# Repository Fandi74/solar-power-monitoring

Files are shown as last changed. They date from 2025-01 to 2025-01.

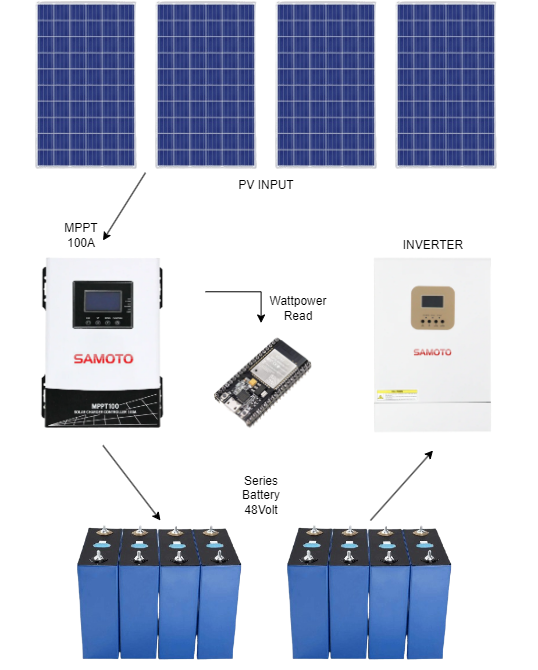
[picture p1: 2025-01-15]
asset/PV.png

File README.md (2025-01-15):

***Solar Monitoring System***

This repository contains the source code for a Solar Monitoring System using ESP32 for data acquisition, storage, and logging. The system reads data from solar panels, calculates power values, and logs the information locally or sends it to the cloud.

**Features**
- Real-time monitoring of voltage, current, and power from two solar panels.
- Data logging to an SD card in JSON format.
- Time synchronization with NTP servers.
- LCD display for live data visualization.
- Modular design with FreeRTOS tasks.

**Project Structure**
- main.cpp: ESP32-based code for the actual deployment.
- hardware/: Contains schematics, footprints PCBs, Simulation.

**Software Dependencies**

- PlatformIO (for development).
- Libraries:
  - Adafruit_ADS1X15
  - ArduinoJson
  - LiquidCrystal_I2C
  - WiFi
  - HTTPClient
  - RTC3231
- Proteus for simulation (using Arduino Uno).

**Future Enhancements**
- Implement cloud integration for remote monitoring.
- Add additional panels and sensors for scalability.
- Enhance data visualization with a web dashboard.

****I Made all of this just for fun****
Feel free give any feedback

**3D PCB**



**Schematic**

Solar Panel Monitoring_page-0001

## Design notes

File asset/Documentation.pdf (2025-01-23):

# com/Fandi74

# Solar Panel Power Monitoring

## Component

### 1. ESP32 WROOVER 32E

The central processing unit of the power monitoring. Manages sensor data collection, data processing, and processing. The ESP32 is responsible for coordinating all the connected components, executing the main program logic, and ensuring that data is accurately read from sensors.

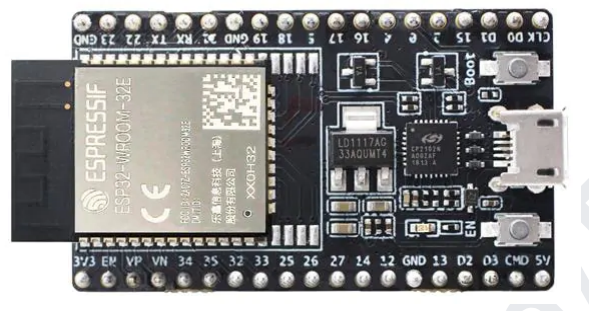
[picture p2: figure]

### 2. Green PCB

The green PCB serves as the foundation of the solar panel power monitoring, ensuring all components are interconnected and can function cohesively. Ensure all

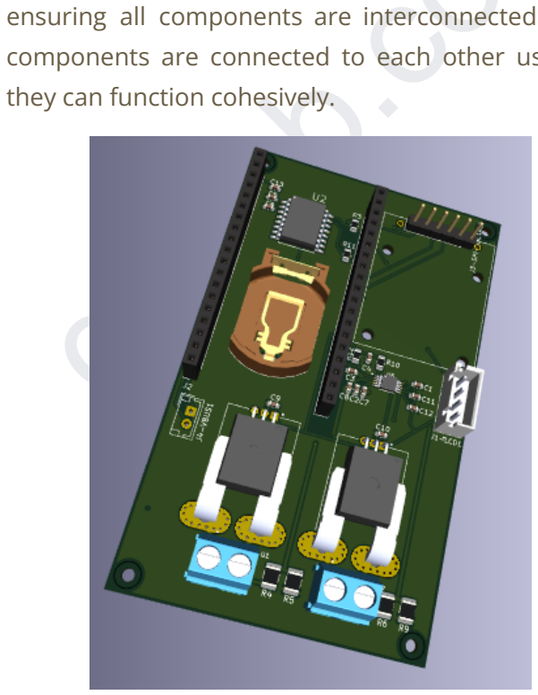
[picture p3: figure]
github.; they can function cohesively.

components are connected to each other using JST and fishbone connectors so that

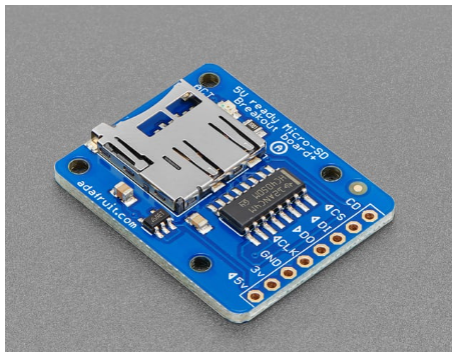
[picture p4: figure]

# com/Fandi74

### 3. Adafruit SD Card Module

A microSD card module is a small device that allows interface a microSD card with the ESP32s. The module enables read from and write to the microSD card, which can be used for storing data such as logs, configuration files, or sensor readings.

### 4. ACS758

ACS758 current sensor is used in solar power monitoring systems to measure the current generated by solar panels. By measuring the current flowing through the wires, the ACS758 provides an analog voltage output proportional to the current. This output is read by a microcontroller like the ESP32 via an ADC, where the data is processed to calculate real-time current.

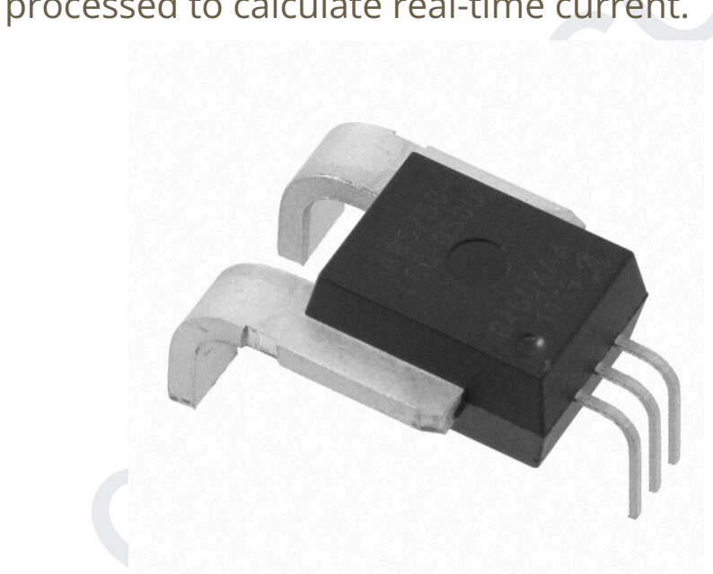
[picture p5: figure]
github.

### 5. DS3231 + CR2023 Battery

The DS3231 is a highly accurate real-time clock (RTC) module. commonly used in embedded systems to keep track of time, even when the main power is turned off. It uses an I2C communication protocol to interface with microcontrollers like the ESP32. The module is powered by a CR2032 coin cell battery, which ensures that the clock continues to run even when the main system power is removed.

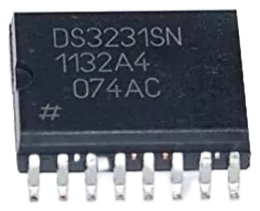
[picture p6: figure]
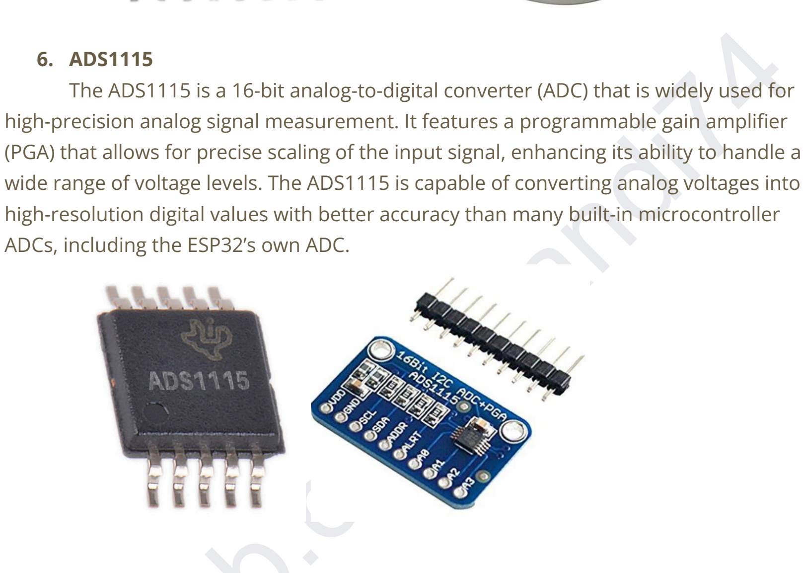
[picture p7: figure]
com/Fandi74; 6. ADS1115; ADCs, including the ESP32’s own ADC.

github.

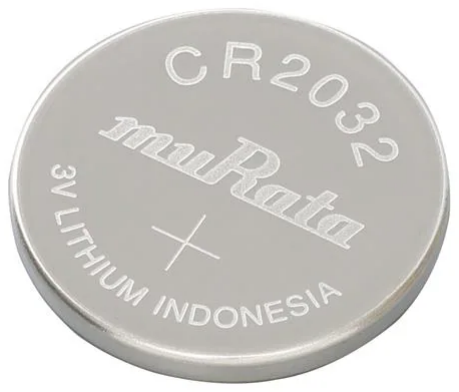
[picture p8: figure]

The ADS1115 is a 16-bit analog-to-digital converter (ADC) that is widely used for high-precision analog signal measurement. It features a programmable gain amplifier (PGA) that allows for precise scaling of the input signal, enhancing its ability to handle a wide range of voltage levels. The ADS1115 is capable of converting analog voltages into high-resolution digital values with better accuracy than many built-in microcontroller

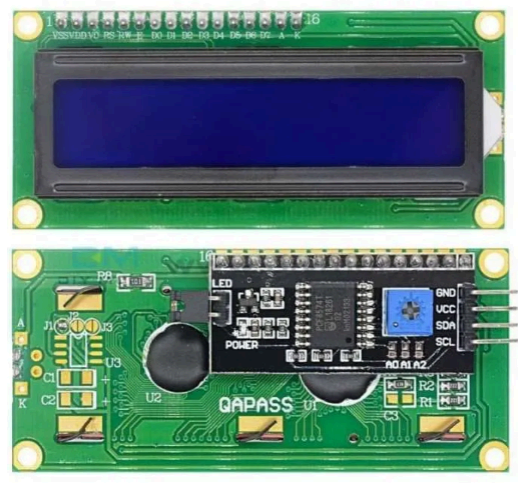
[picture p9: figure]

### 7. LCD I2C

An I2C LCD is an LCD (Liquid Crystal Display) that uses the I2C (Inter-Integrated Circuit) communication protocol for data transfer. This simplifies wiring and reduces the number of pins needed compared to traditional parallel LCDs.

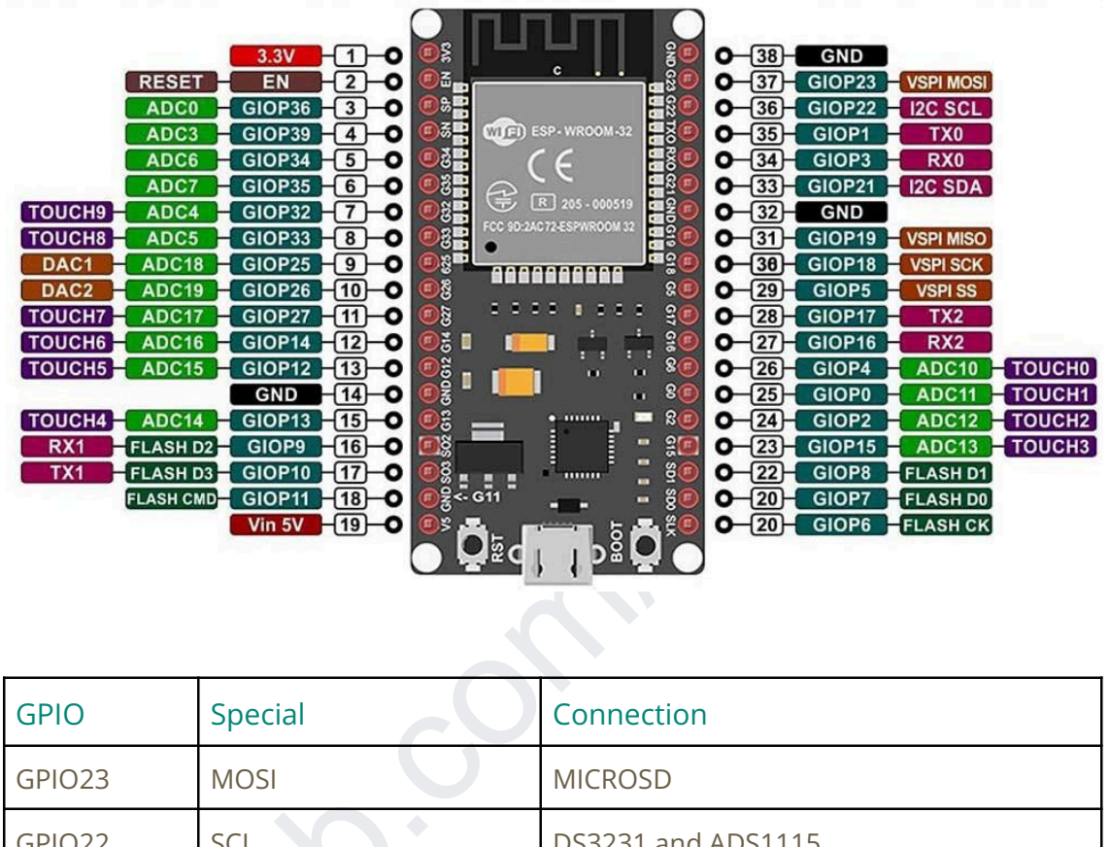
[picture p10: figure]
com/Fandi74; GPIO; Special; Connection; GPIO23; MOSI; MICROSD

github.

## Device Configuration

## ESP32 Configuration

GPIO22 | SCL | DS3231 and ADS1115
GPIO21 | SDA | DS3231 and ADS1115
GPIO19 | MISO | MICROSD
GPIO18 | SCK | MICROSD
GPIO5 | SS | MICROSD
GPIO15 | Alert | ADS1115 Alert

# com/Fandi74

## ADS1115 Configuration

GPIO | Special | Connection
A0 | Channel 0 | VDC SOLAR PANEL 1
A1 | Channel 1 | VDC SOLAR PANEL 2
A2 | Channel 2 | ACS VIOUT 1
A3 | Channel 3 | ACS VIOUT 2

## Block Diagram

## Solar Panel System Diagram

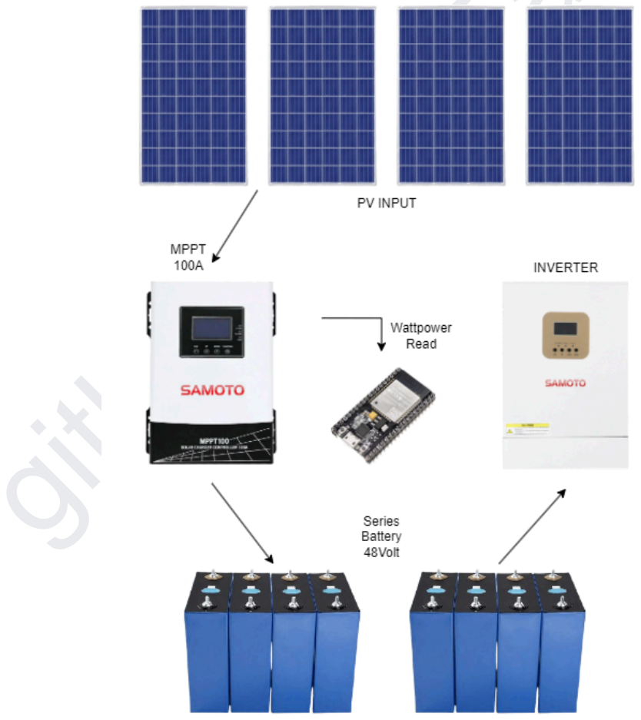
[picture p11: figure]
github.

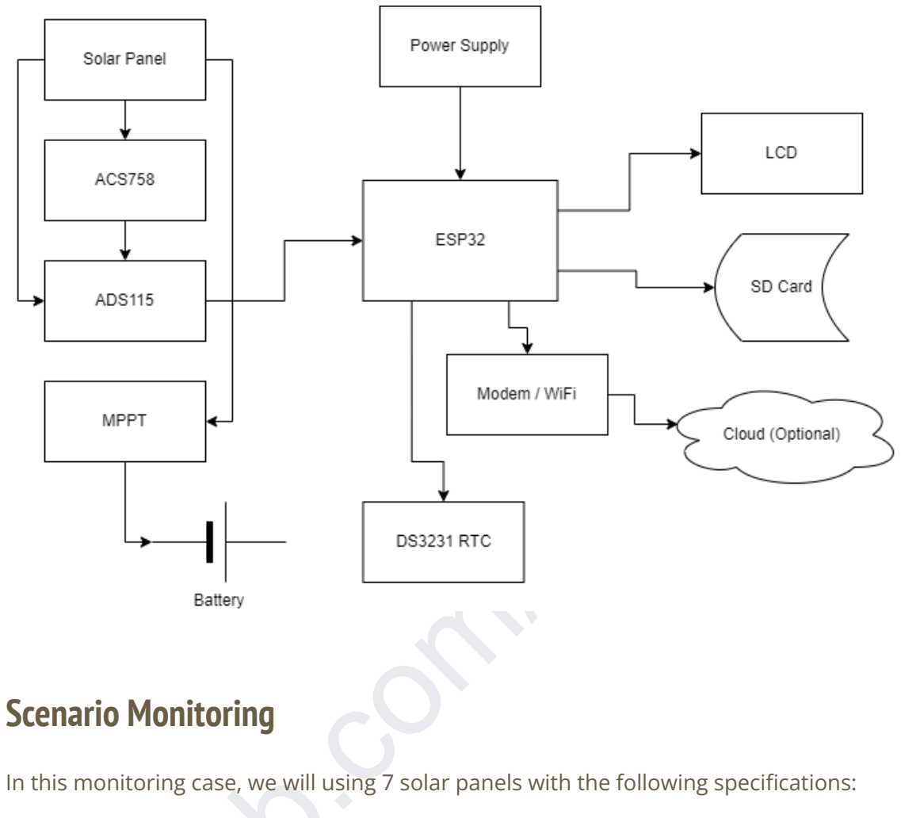
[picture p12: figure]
com/Fandi74; Scenario Monitoring

github.

## ESP32 Power Monitoring Diagram

In this monitoring case, we will using 7 solar panels with the following specifications:

Note: In this scenario ignoring power loss which mean efficiency close to 100%

- Power: 580 Wp
- Maximum Power Voltage (Vmpp): 44.06 V
- Maximum Power Current (Impp): 13.17 A

## Two Source Codes: One for Arduino (Proteus Simulation) and One for ESP32

I'm using 2 source code microcontroller platforms, first Arduino (for simulation in Proteus) and ESP32 (for real-world application). Arduino simulation designed to simulate the behavior of the solar panel system in Proteus using an Arduino board. ESP32 microcontroller, which is used for real-world applications to monitor the solar panel system in a fully functional setup.

github.

# com/Fandi74

### Scenario Breakdown

1. Connecting Panels in Parallel:
- When connecting solar panels in parallel, the voltage remains the same, but the current is the sum of the currents from each panel.
- In this case, I use 7 panels in parallel. The voltage across all the panels will be the same as the individual panel voltage, which is 44.06 V (Vmpp).
- The current will be the sum of the maximum power currents of each panel:
- [ I totall = 7 x 13.17 A = 92.19A ]
2. Total Power Output:
- The total power of the 7 panels can be calculated as:
- [ Ptotal=7×580 W=4060 WP ]
- So the total power output from the 7 panels in parallel is 4060 W (4.06 kW).
3. Solar Power Monitoring Considerations:
- Voltage Measurement: To monitor the voltage of the solar panel array, we can use a voltage sensor (like a voltage divider or an analog-to-digital converter such as ADS1115) to measure the voltage at the output. The voltage will be around 44.06 V (the Vmpp).
- Current Measurement: To measure the current, we can use a current sensor (like the ACS758) to measure the output current. Since the panels are in parallel, the total current is 92.19 A if we take 100% efficiency.
- Power Calculation: Once we have the voltage and current readings, wecan calculate the power output of the system at any moment using the formula: P = V I
4. Monitoring System Components:
- Microcontroller ESP32 used to read the analog signals from the voltage and current sensors (using an ADC like ADS1115) and process the data. The ESP32 can then display the real-time data on an LCD screen.
5. Real-Time Monitoring:
- Voltage: The ESP32 will regularly measure and report the voltage output from the panels, which should be close to the 44.06 V (Vmpp) when the system is operating at maximum power.
- Current: The total current (92.19 A) will be monitored, and we can track whether the current is in line with the expected output.
- Power: Based on the current and voltage, the power being generated by the panels can be calculated and displayed or logged for future analysis.

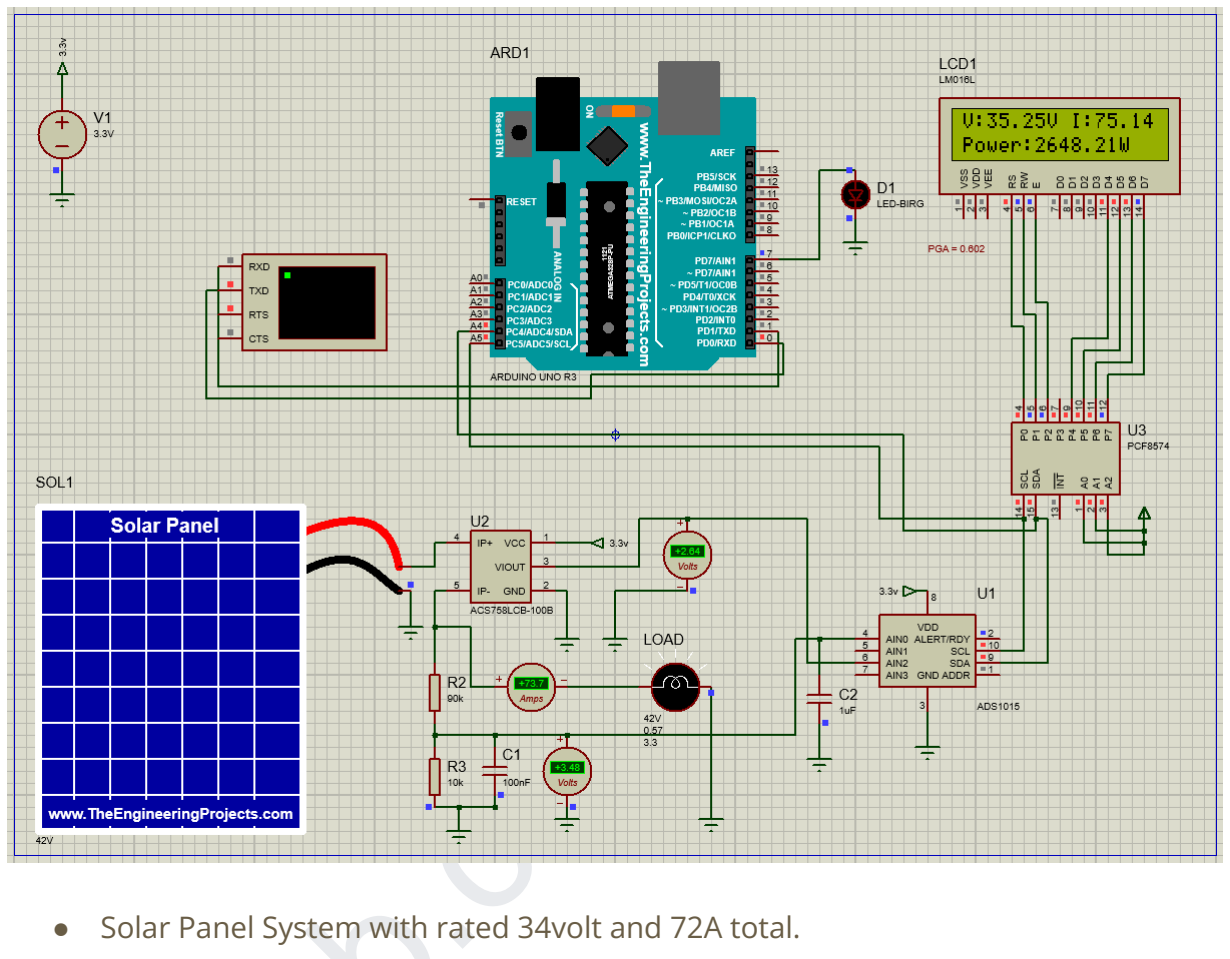
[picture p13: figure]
com/Fandi74

github.

## Proteus Simulation

In this simulation, I use an Arduino board instead of the ESP32, as Proteus has limitations when simulating the ESP32. Using an Arduino board offers flexibility for simulating basic functionalities such as reading sensors and processing data.

- Solar Panel System with rated 34volt and 72A total.
- Components in the Simulation:
- ACS758 - Used to measure the current output from the solar panels. The ACS758 will give an analog output that varies with the current.
- Voltage Divider: A voltage divider circuit will be used to measure the high voltage with R1 90K and R2 10K, from the solar panel and reduce it to a level that the Arduino can safely read.
- ADS1115 ADC: In a real system, use an ADS1115 to get precise readings of voltage and current. However, in this simulation, I connect both the divider output and acs758 to ADS Channel.
- LCD or Serial Monitor: To display the real-time data, Voltage, Current and total power.

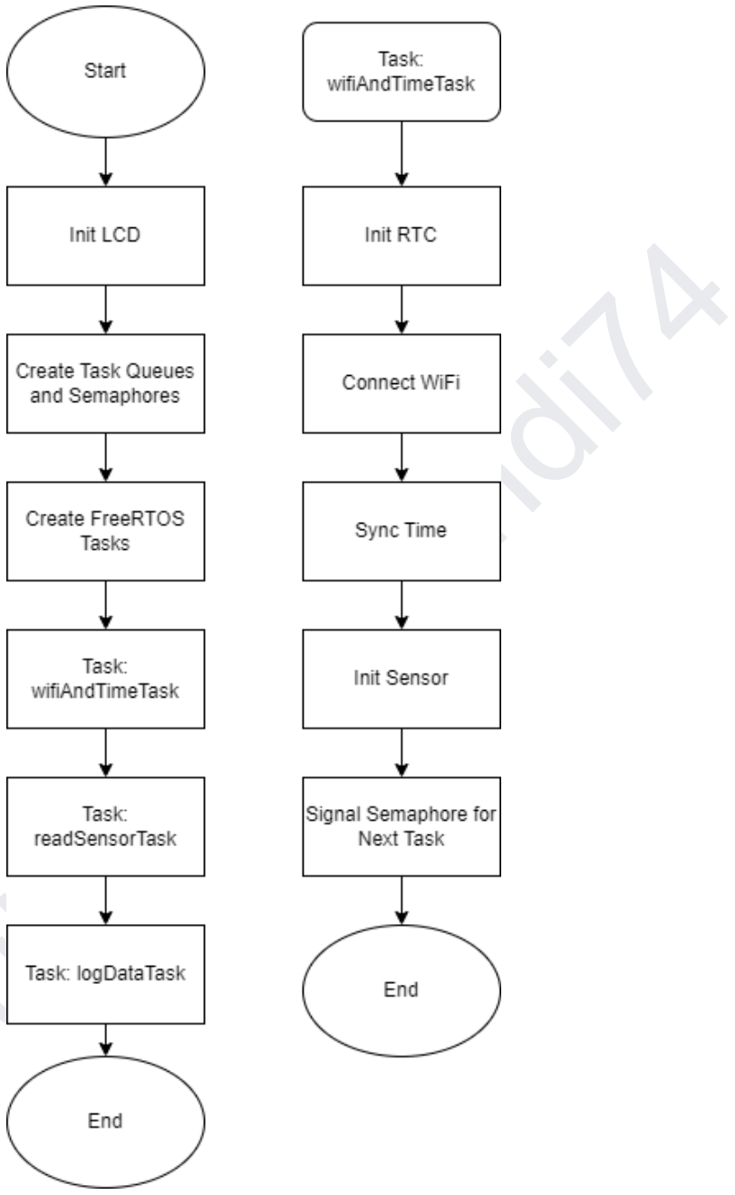
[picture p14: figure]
com/Fandi74

github.

## Flowchart (ESP32)

## Limitations in Proteus

- No ESP32 Support: Since Proteus has limitations with simulating the ESP32, I use the Arduino instead, which has decent support for simulation in Proteus.
- Simpler Simulation: While I am not able to use some of the advanced features of the ESP32, the Arduino can still handle the basic simulation of sensors, voltage dividers, and displaying data.

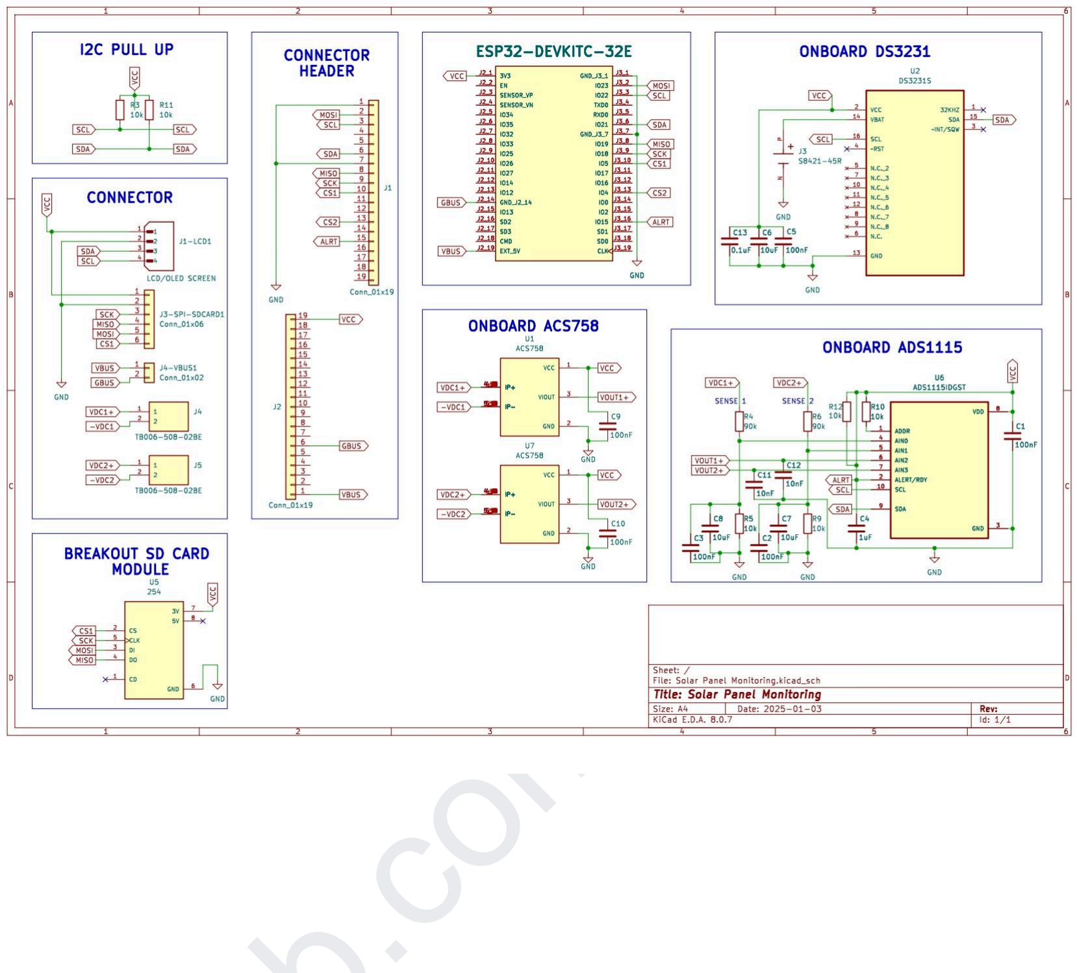
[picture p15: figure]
com/Fandi74

github.

# Schematic

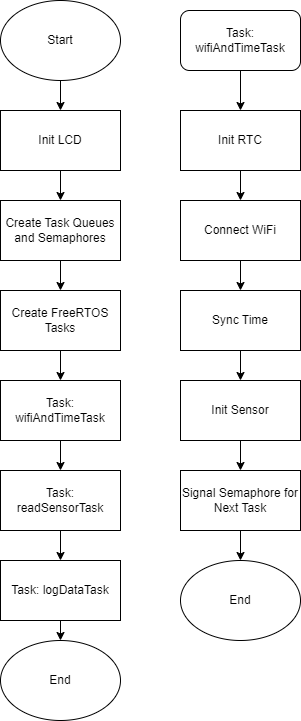
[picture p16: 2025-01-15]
asset/solar panel flowchart.drawio.png

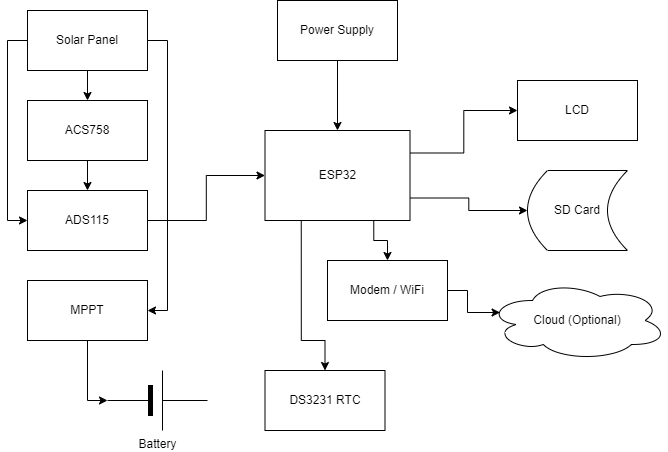
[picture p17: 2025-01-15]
asset/Block Diagram .drawio.png

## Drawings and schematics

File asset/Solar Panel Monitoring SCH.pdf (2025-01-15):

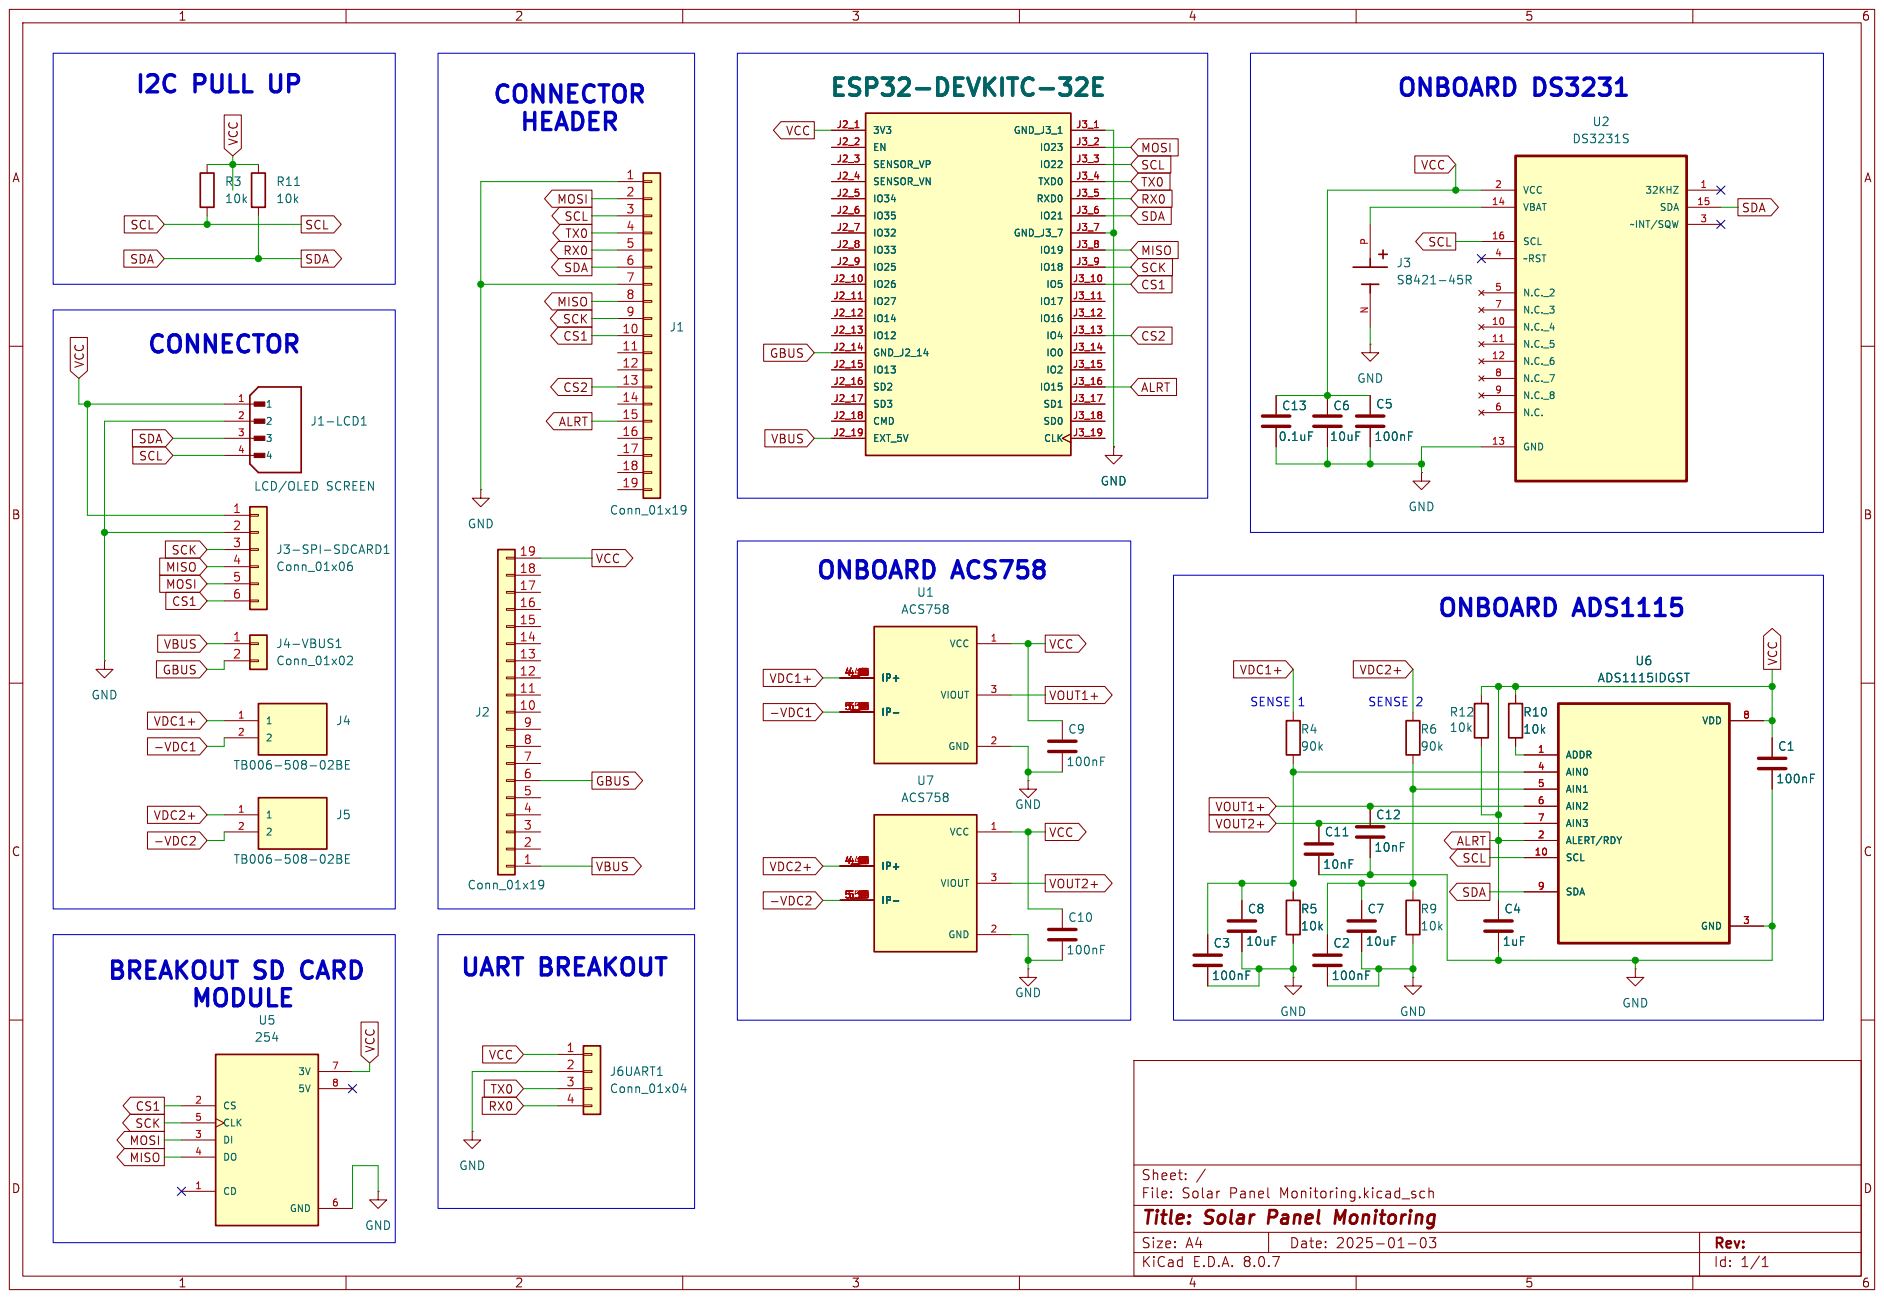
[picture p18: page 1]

MOSI SCL ALRT CS1 MISO

Id: 1/1 Title: Solar Panel Monitoring

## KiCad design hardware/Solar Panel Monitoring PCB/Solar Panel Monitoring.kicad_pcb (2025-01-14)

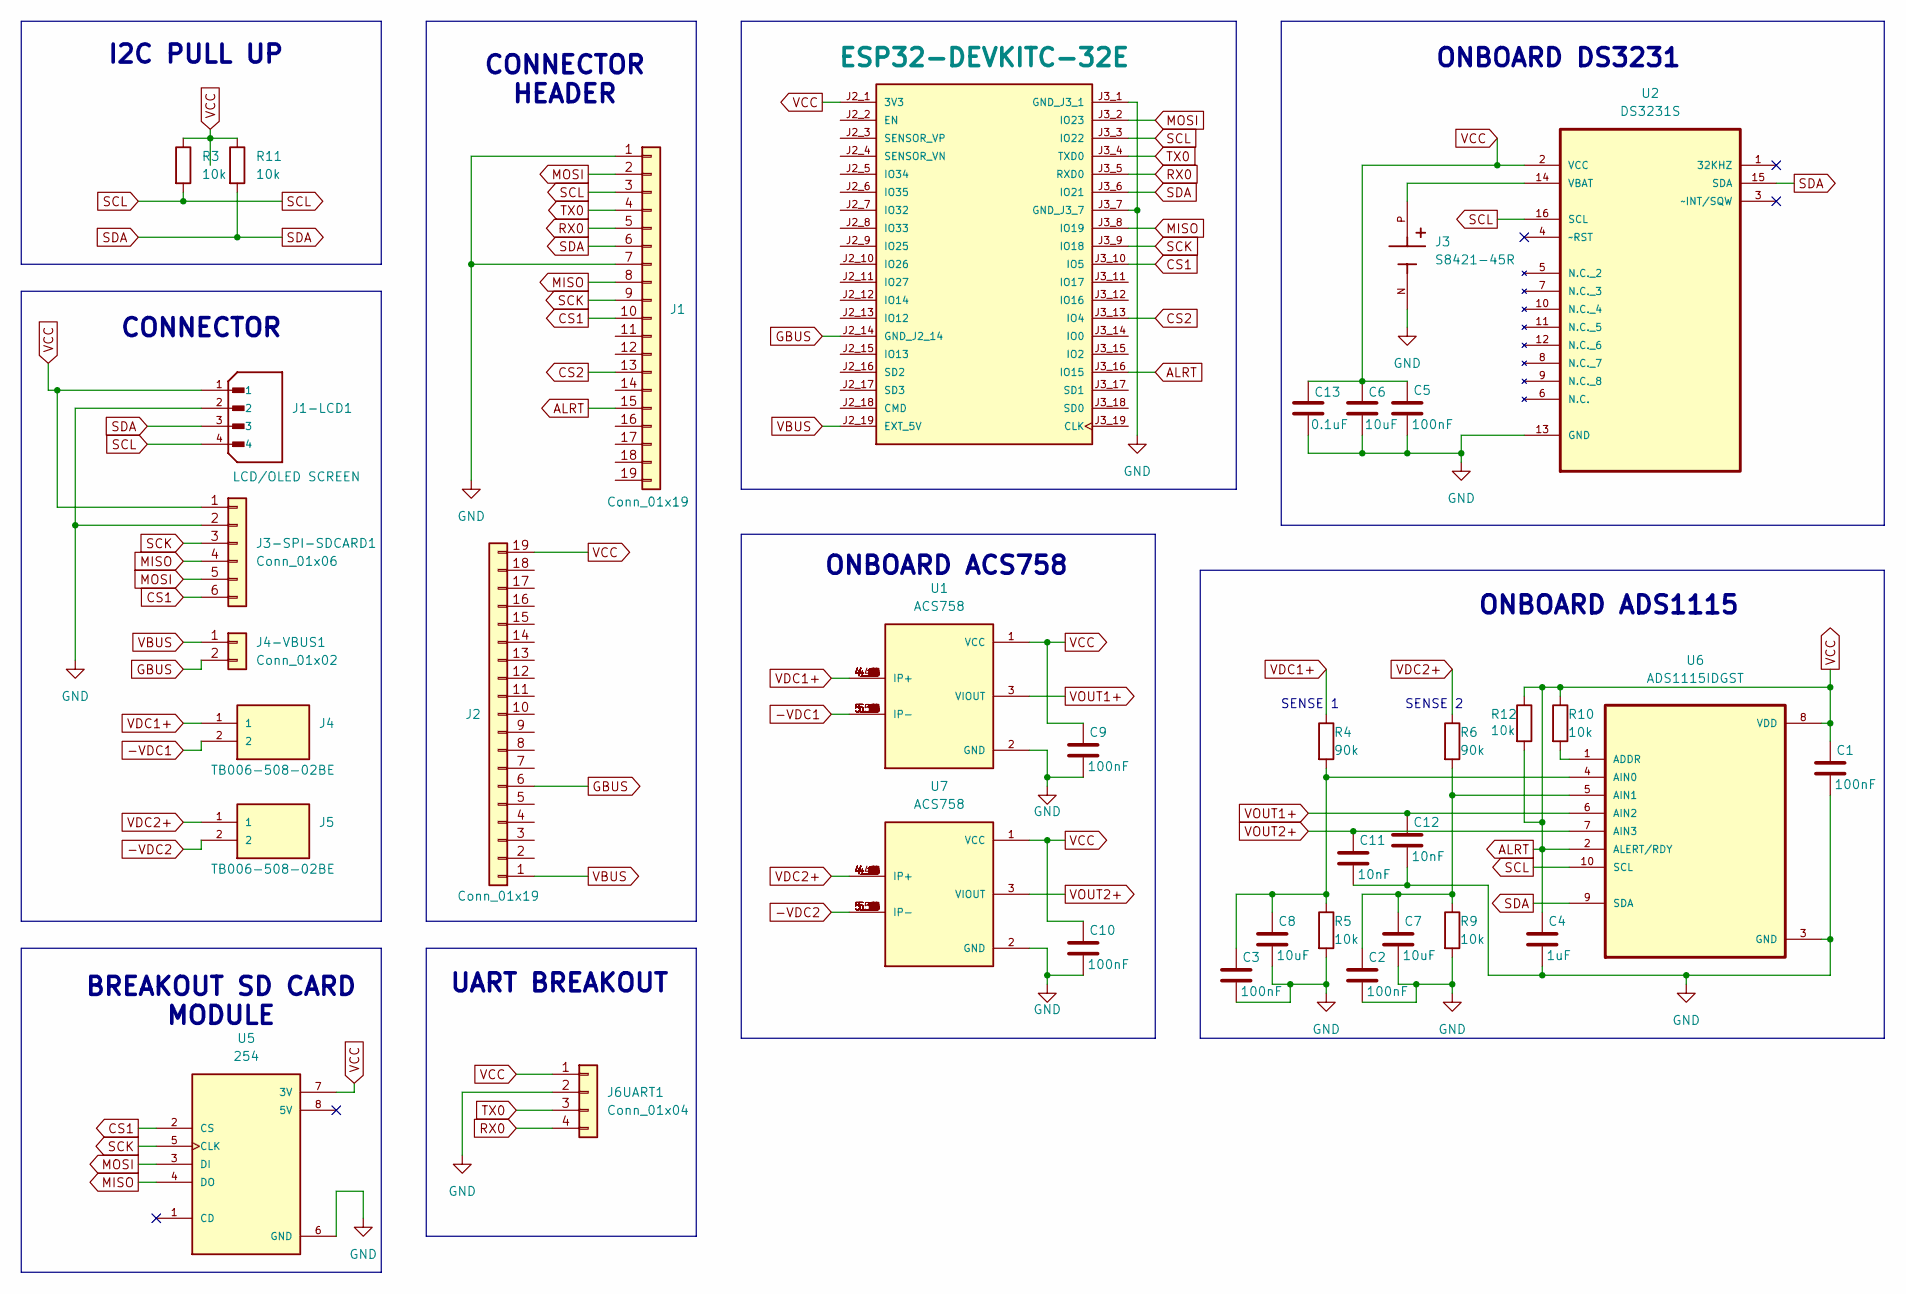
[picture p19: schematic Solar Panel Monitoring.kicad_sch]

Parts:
C1, C2, C3, C5, C9, C10: 100nF; C_0603_1608Metric
C4: 1uF; C_0603_1608Metric
C6, C7, C8: 10uF; C_0603_1608Metric
C11, C12: 10nF; C_0603_1608Metric
C13: 0.1uF; C_0603_1608Metric
J1, J2: Conn_01x19; PinSocket_1x19_P2.54mm_Vertical
J1-LCD1: LCD/OLED SCREEN; JST_B4B-XH-A_LF__SN_; PARTREV 7/4/21
J3: S8421-45R; HARWIN_S8421-45R; PARTREV 7
J3-SPI-SDCARD1: Conn_01x06; PinHeader_1x06_P2.54mm_Vertical
J4, J5: TB006-508-02BE; CUI_TB006-508-02BE
J4-VBUS1: Conn_01x02; JST_EH_B02B-EH-A_02x2.50mm_Straight
J6UART1: Conn_01x04; PinHeader_1x04_P2.54mm_Vertical
R3, R10, R11, R12: 10k; R_0805_2012Metric_Pad1.20x1.40mm_HandSolder
R4, R6: 90k; R_1210_3225Metric_Pad1.30x2.65mm_HandSolder
R5, R9: 10k; R_1210_3225Metric_Pad1.30x2.65mm_HandSolder
U1, U7: ACS758; XDCR_ACS758; PARTREV 12
U2: DS3231S; SOIC127P1032X265-16N; MPN DS3231S#
U4: ESP32-DEVKITC-32E; MODULE_ESP32-DEVKITC-32E; PARTREV 1.4
U5: 254; MODULE_254; PARTREV Jul 31, 2013
U6: ADS1115IDGST; SOP50P490X110-10N

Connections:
-VDC1: J4.2, U1.5 (IP-), U1.5_1 (IP-), U1.5_2 (IP-), U1.5_3 (IP-), U1.5_4 (IP-), U1.5_5 (IP-), U1.5_6 (IP-), U1.5_7 (IP-), U1.5_8 (IP-), U1.5_9 (IP-), U1.5_10 (IP-), U1.5_11 (IP-), U1.5_12 (IP-), U1.5_13 (IP-), U1.5_14 (IP-), U1.5_15 (IP-), U1.5_16 (IP-)
-VDC2: J5.2, U7.5 (IP-), U7.5_1 (IP-), U7.5_2 (IP-), U7.5_3 (IP-), U7.5_4 (IP-), U7.5_5 (IP-), U7.5_6 (IP-), U7.5_7 (IP-), U7.5_8 (IP-), U7.5_9 (IP-), U7.5_10 (IP-), U7.5_11 (IP-), U7.5_12 (IP-), U7.5_13 (IP-), U7.5_14 (IP-), U7.5_15 (IP-), U7.5_16 (IP-)
ALRT: C1.2, C4.2, C5.2, C6.2, C9.2, C10.2, C13.2, J1.15, J1-LCD1.1, J2.19, J3-SPI-SDCARD1.1, J6UART1.1, R3.1, R10.1, R11.1, R12.1, R12.2, U1.1 (VCC), U2.2 (VCC), U4.J2_1 (3V3), U4.J3_16 (IO15), U5.7 (3V), U6.2 (ALERT/RDY), U6.8 (VDD), U7.1 (VCC); also elsewhere on the board
CS1: J1.10, J3-SPI-SDCARD1.6, U4.J3_10 (IO5), U5.2 (CS)
CS2: J1.13, U4.J3_13 (IO4)
GBUS: J2.6, J4-VBUS1.2, U4.J2_14 (GND_J2_14)
GND: C1.1, C2.1, C3.1, C4.1, C5.1, C6.1, C7.1, C8.1, C9.1, C10.1, C11.1, C12.1, C13.1, J1.1, J1.7, J1-LCD1.2, J3.N, J3-SPI-SDCARD1.2, J6UART1.2, R5.2, R9.2, U1.2 (GND), U2.13 (GND), U4.J3_1 (GND_J3_1), U4.J3_7 (GND_J3_7), U5.6 (GND), U6.3 (GND), U7.2 (GND); also elsewhere on the board
MISO: J1.8, J3-SPI-SDCARD1.4, U4.J3_8 (IO19), U5.4 (DO)
MOSI: J1.2, J3-SPI-SDCARD1.5, U4.J3_2 (IO23), U5.3 (DI)
unnamed: J3.P, U2.14 (VBAT)
unnamed: R10.2, U6.1 (ADDR)
unnamed: C3.2, C8.2, R4.2, R5.1, U6.4 (AIN0)
unnamed: C2.2, C7.2, R6.2, R9.1, U6.5 (AIN1)
RX0: J1.5, J6UART1.4, U4.J3_5 (RXD0); also elsewhere on the board
SCK: J1.9, J3-SPI-SDCARD1.3, U4.J3_9 (IO18), U5.5 (CLK)
SCL: J1.3, J1-LCD1.4, R3.2, U2.16 (SCL), U4.J3_3 (IO22), U6.10 (SCL)
SDA: J1.6, J1-LCD1.3, R11.2, U2.15 (SDA), U4.J3_6 (IO21), U6.9 (SDA)
TX0: J1.4, J6UART1.3, U4.J3_4 (TXD0); also elsewhere on the board
VBUS: J2.1, J4-VBUS1.1, U4.J2_19 (EXT_5V)
VDC1+: J4.1, R4.1, U1.4 (IP+), U1.4_1 (IP+), U1.4_2 (IP+), U1.4_3 (IP+), U1.4_4 (IP+), U1.4_5 (IP+), U1.4_6 (IP+), U1.4_7 (IP+), U1.4_8 (IP+), U1.4_9 (IP+), U1.4_10 (IP+), U1.4_11 (IP+), U1.4_12 (IP+), U1.4_13 (IP+), U1.4_14 (IP+), U1.4_15 (IP+), U1.4_16 (IP+)
VDC2+: J5.1, R6.1, U7.4 (IP+), U7.4_1 (IP+), U7.4_2 (IP+), U7.4_3 (IP+), U7.4_4 (IP+), U7.4_5 (IP+), U7.4_6 (IP+), U7.4_7 (IP+), U7.4_8 (IP+), U7.4_9 (IP+), U7.4_10 (IP+), U7.4_11 (IP+), U7.4_12 (IP+), U7.4_13 (IP+), U7.4_14 (IP+), U7.4_15 (IP+), U7.4_16 (IP+)
VOUT1+: C12.2, U1.3 (VIOUT), U6.6 (AIN2)
VOUT2+: C11.2, U6.7 (AIN3), U7.3 (VIOUT)

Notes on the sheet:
SENSE 2
CONNECTOR HEADER
I2C PULL UP
SENSE 1
ONBOARD ADS1115
CONNECTOR
ONBOARD ACS758
BREAKOUT SD CARD MODULE
UART BREAKOUT
ONBOARD DS3231

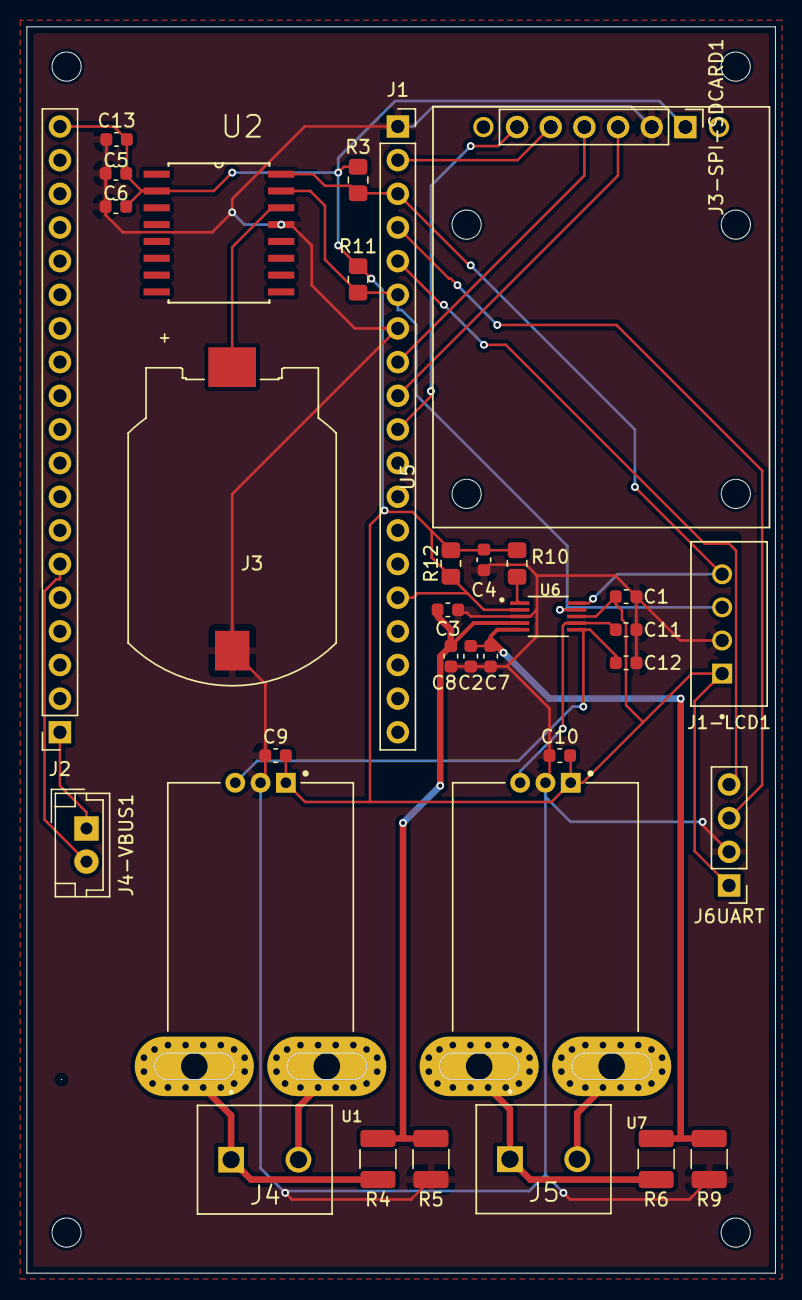
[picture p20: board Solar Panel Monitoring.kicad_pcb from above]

Board: 2 copper layers, 56.5 x 94.1 mm, 35 parts (0 on the bottom side), 22 nets.

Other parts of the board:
J6UART: Conn_01x04; PinHeader_1x04_P2.54mm_Vertical

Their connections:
ALRT: J6UART.1; also elsewhere on the board
GND: J6UART.2; also elsewhere on the board
RX0: J6UART.4; also elsewhere on the board
TX0: J6UART.3; also elsewhere on the board

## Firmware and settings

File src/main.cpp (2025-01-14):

#include <Arduino.h>
#include <Adafruit_INA219.h>
#include <ArduinoJson.h>
// #include <ESP32Time.h>
#include <LiquidCrystal_I2C.h>
#include <HTTPClient.h>
#include <RTC3231.h>
#include <SD.h>
#include <WiFi.h>
#include <Wire.h>
#include <Adafruit_ADS1X15.h>

// ADS Channel 0 = SOLAR PANEL 1 VOLTAGE
// ADS Channel 1 = SOLAR PANEL 2 VOLTAGE
// ADS Channel 2 = ACS758 CURRENT SOLAR PANEL 1
// ADS Channel 3 = ACS758 CURRENT SOLAR PANEL 2

// Variable Definitions
#define SERIAL_BAUD 115200
#define I2C_SDA_PIN 21
#define I2C_SCL_PIN 22
#define I2C_FREQ 100000

#define PGA 0.602
#define ACSOFFSET 1.67
#define ACSSENS 0.0134
#define LSB 0.0000763

// GPIO Definitions
#define sdChipSelect 5

// Wi-Fi Credentials
const char* ssid = "your_ssid";
const char* password = "your_password";

#define DATA_SAVE_SERVER "thingsboard.cloud"  // only for example
String DATA_SAVE_RESOURCE_API_KEY = "xxxxx";  // dummy api key
#define DATA_SAVE_PORT 80                     // only for example
#define DATA_SAVE_RESOURCE_PRE "/api/v1/"
#define DATA_SAVE_RESOURCE_POST "/telemetry"
#define GSM_APN_DEFAULT_1 "Internet"       //"Internet" for telkomsel
#define GSM_CONNECTION_TIMEOUT_MS 120000L  // 120 detik
#define MAX_DATA_SAVED 30

#define DATA_VALUES_KEY "values"
#define DATA_TIMESTAMP_KEY "ts"
#define DATA_READING_ID_KEY "rid"

#define DATA_VOLTAGE1_KEY "vgn1"
#define DATA_CURRENT1_KEY "crn1"
#define DATA_POWER1_KEY "pwr1"

#define DATA_VOLTAGE2_KEY "vgn2"
#define DATA_CURRENT2_KEY "crn2"
#define DATA_POWER2_KEY "pwr2"

// GLOBAL VAR
uint16_t rawAds0 = 0;
uint16_t rawAds1 = 0;
uint16_t rawAds2 = 0;
uint16_t rawAds3 = 0;

float voltageAds0 = 0;
float voltageAds1 = 0;
float voltageAds2 = 0;
float voltageAds3 = 0;

float currentAcs1 = 0;
float currentAcs2 = 0;

float powerSP1 = 0;
float powerSP2 = 0;

uint32_t lastReadingID;
uint16_t dataIndex = 0;

struct Data {  // Structure declaration
  uint32_t readingID[MAX_DATA_SAVED];
  uint64_t readingUnixTime[MAX_DATA_SAVED];
};
typedef struct {
  uint32_t readID;
  float voltageRead1;
  float currentRead1;
  float powerSP1;

  float voltageRead2;
  float currentRead2;
  float powerSP2;
  unsigned long long timeUnix;
} SensorData;

const char* ntpServer = "pool.ntp.org";
const long gmtOffset_sec = 0;         // Offset in seconds from GMT
const int daylightOffset_sec = 3600;  // Daylight offset in seconds (e.g., 3600 for 1 hour)

// ESP32Time rtc(0);
Adafruit_INA219 ina219;
LiquidCrystal_I2C lcd(0x27, 20, 4);
RTC_DS3231 rtc;
File dataFile;
HTTPClient http;
Adafruit_ADS1115 ads;

float current_mA = 0;
float busvoltage = 0;
float loadvoltage = 0;
char Request[1000];
DynamicJsonDocument saveData(1024);

TaskHandle_t wifiAndTimeTaskHandle;
TaskHandle_t readSensorTaskHandle;
TaskHandle_t logDataTaskHandle;
QueueHandle_t SendQueue;

SemaphoreHandle_t task1Semaphore;
SemaphoreHandle_t task2Semaphore;

SensorData savedData;
SensorData receivedData;

/**
 * Connects to the WiFi network using the provided SSID and password.
 * Continuously attempts to connect until successful, indicated by 
 * a change in the WiFi status to WL_CONNECTED. During the connection
 * attempt, a dot is printed to the serial monitor every 500 milliseconds.
 * Once connected, it prints a confirmation message to the serial monitor.
 */

void connectToWifi() {
  WiFi.begin(ssid, password);
  while (WiFi.status() != WL_CONNECTED) {
    delay(500);
    Serial.print(".");
  }
  Serial.println("");
  Serial.println("WiFi connected");
}


/**
 * @brief Initializes the LCD display.
 * 
 * This function performs the initial setup for the LCD display by initializing it,
 * turning on the backlight, clearing any previous content, and displaying an
 * "Initializing..." message for 2 seconds.
 */

void initLcd() {
  lcd.init();
  lcd.backlight();
  lcd.clear();
  lcd.print("Initializing...");
  delay(2000);
}

/**
 * @brief Reads the raw ADC value from the ADS1115.
 * @param channel The ADS1115 channel to read from.
 * @return The raw ADC value.
 */
float getRawAds(int channel) {
  return ads.readADC_SingleEnded(channel);
}

/**
 * @brief Reads the voltage from the ADS1115.
 * @param channel The ADS1115 channel to read from.
 * @return The voltage from the ADS1115 in volts.
 */
float getVoltageAds(int channel) {
  float voltage = getRawAds(channel) * LSB / PGA;
  return voltage * 10;
}

/**
 * @brief Calculates the current from a raw ADC value.
 * 
 * This function takes the raw ADC value from the ACS712 and calculates the
 * current in amps.
 * 
 * @param raw The raw ADC value from the ACS712.
 * @return The current in amps.
 */
float getCurrentFromRaw(int raw){
  float realVolt2 = (raw * LSB) / PGA;
  return (realVolt2 - ACSOFFSET) / ACSSENS;
}

/**
 * @brief Calculates the electrical power based on current and voltage.
 * 
 * This function computes the power by multiplying the provided current 
 * (in amps) and voltage (in volts).
 * 
 * @param current The current in amps.
 * @param voltage The voltage in volts.
 * @return The calculated power in watts.
 */
float getPower(float current, float voltage){
  return current * voltage;
}

/**
 * @brief Reads sensor data from the ADS1115 and ACS712 sensors.
 * 
 * This function retrieves voltage readings from four ADS1115 channels and 
 * computes the corresponding current values using the ACS712 sensors. It 
 * then calculates the power values for two channels by multiplying the 
 * current and voltage readings. The voltage, current, and power values 
 * are displayed on the serial monitor and updated on an LCD screen.
 */
void readSensor(){
  voltageAds0 = getVoltageAds(0);
  voltageAds1 = getVoltageAds(1);
  voltageAds2 = getVoltageAds(2);
  voltageAds3 = getVoltageAds(3);
  vTaskDelay(10 / portTICK_PERIOD_MS);

  currentAcs1 = getCurrentFromRaw(getRawAds(2));
  currentAcs2 = getCurrentFromRaw(getRawAds(3));

  vTaskDelay(10 / portTICK_PERIOD_MS);

  powerSP1 = getPower(currentAcs1, voltageAds0);
  powerSP2 = getPower(currentAcs2, voltageAds1);

  Serial.println("V0: " + String(voltageAds0));
  Serial.println("V1: " + String(voltageAds1));
  Serial.println("V2: " + String(voltageAds2));
  Serial.println("V3: " + String(voltageAds3));
  Serial.println("I1: " + String(currentAcs1));
  Serial.println("I2: " + String(currentAcs2));
  Serial.println("P1: " + String(powerSP1));
  Serial.println("P2: " + String(powerSP2));

  // Update LCD
  lcd.clear();
  lcd.setCursor(0, 0);
  lcd.printf("V1:%.2fV", voltageAds0);
  lcd.setCursor(9, 0);
  lcd.printf("I1:%.2fA", currentAcs1);
  lcd.setCursor(0, 1);
  lcd.printf("P1:%.2fW", powerSP1);

  lcd.setCursor(0, 2);
  lcd.printf("V2:%.2fV", voltageAds1);
  lcd.setCursor(9, 2);
  lcd.printf("I2:%.2fA", currentAcs2);
  lcd.setCursor(0, 3);
  lcd.printf("P2:%.2fW", powerSP2);
}

/**
 * @brief Saves sensor data into a global structure and queues it for further processing.
 * 
 * This function retrieves the current Unix timestamp and scales it to milliseconds. It then populates 
 * a global SensorData structure with the latest readings for voltage, current, and power from two 
 * channels, along with the timestamp and a unique reading ID. The updated reading ID is incremented 
 * for future use. The function attempts to send this data to a queue for further processing, logging 
 * success or failure to the serial monitor.
 */
void saveDataSensor(){
  unsigned long long timestem = time(nullptr);
  unsigned long long timestem2 = timestem * 1000ULL;
  Serial.println("Epoch Time Before : " + String(timestem));
  Serial.println("Epoch Time After : " + String(timestem2));
  savedData.readID = lastReadingID;

  savedData.timeUnix = timestem2;
  savedData.voltageRead1 = voltageAds0;
  savedData.voltageRead2 = voltageAds1;
  savedData.currentRead1 = currentAcs1;
  savedData.currentRead2 = currentAcs2;
  savedData.powerSP1 = powerSP1;
  savedData.powerSP2 = powerSP2;

  lastReadingID++;

  if (xQueueSend(SendQueue, &savedData, portMAX_DELAY) != pdPASS) {
    Serial.println("Failed to input data to queue");
  } else {
    Serial.println("Data sent to queue successfully");
  }
}

/**
 * @brief Stores sensor data from queue to SD card log file.
 * 
 * This function opens an SD card log file in append mode and waits for data to be sent to a queue. 
 * Upon receiving data, it extracts the latest voltage, current, and power readings from two channels, 
 * along with the corresponding reading ID and Unix timestamp. It then constructs a JSON string 
 * from this data and writes it to the log file. The function also logs the data to the serial monitor.
 */
void storeData() {
  File logFile = SD.open("/log.txt", FILE_APPEND);
  if (!logFile) {
    Serial.println("Failed to open log file!");
    vTaskDelete(NULL);
  }

  if (xQueueReceive(SendQueue, &receivedData, portMAX_DELAY) == pdPASS) {
    saveData[DATA_VALUES_KEY][DATA_READING_ID_KEY] = receivedData.readID;
    saveData[DATA_VALUES_KEY][DATA_VOLTAGE1_KEY] = receivedData.voltageRead1;
    saveData[DATA_VALUES_KEY][DATA_CURRENT1_KEY] = receivedData.currentRead1;
    saveData[DATA_VALUES_KEY][DATA_POWER1_KEY] = receivedData.powerSP1;

    saveData[DATA_VALUES_KEY][DATA_VOLTAGE2_KEY] = receivedData.voltageRead2;
    saveData[DATA_VALUES_KEY][DATA_CURRENT2_KEY] = receivedData.currentRead2;
    saveData[DATA_VALUES_KEY][DATA_POWER2_KEY] = receivedData.powerSP2;

    saveData[DATA_TIMESTAMP_KEY] = receivedData.timeUnix;

    size_t jsonSize = measureJson(saveData);
    String jsonString;
    serializeJson(saveData, jsonString);

    // Write to SD Card
    logFile.println(jsonString);
    logFile.flush();
    Serial.println("Logged: " + jsonString);

    vTaskDelay(200 / portTICK_PERIOD_MS);
  }
}

/**
 * @brief Task for initializing the Real Time Clock (RTC), connecting to WiFi, and
 *        setting the system time from an NTP server.
 *
 * This task initializes the RTC and attempts to connect to WiFi. If the RTC and
 * WiFi connections are successful, it sets the system time from an NTP server and
 * initializes the INA219 sensor. If any of these steps fail, the task halts the
 * system with a descriptive error message on the LCD screen and serial monitor.
 */
void wifiAndTimeTask(void* parameter) {
  Wire.begin((I2C_SDA_PIN, I2C_SCL_PIN, I2C_FREQ));
  vTaskDelay(1000 / portTICK_PERIOD_MS);
  if (!rtc.begin(&Wire)) {
    lcd.setCursor(0, 1);
    lcd.print("RTC FAIL!");
    Serial.println("Couldn't find RTC!");
    while (1);  // Halt system if RTC fails
  } else {
    lcd.clear();
    lcd.setCursor(0, 1);
    lcd.print("RTC OK!");
  }

  vTaskDelay(1000 / portTICK_PERIOD_MS);

  connectToWifi();
  struct tm timeinfo;
  while (!getLocalTime(&timeinfo)) {
    Serial.print(".");
    delay(1000);
  }

  time_t now = time(nullptr);
  DateTime dt(now);
  rtc.adjust(dt);
  Serial.print("Epoch time: ");
  Serial.println(now);

  lastReadingID = 0;
  dataIndex = 0;

  configTime(gmtOffset_sec, daylightOffset_sec, ntpServer);

  vTaskDelay(1000 / portTICK_PERIOD_MS);

  if (!ina219.begin(&Wire)) {
    lcd.setCursor(0, 1);
    lcd.print("INA219 FAIL!");
    Serial.println("Failed to initialize INA219!");
    while (1);
  } else {
    lcd.clear();
    lcd.setCursor(0, 1);
    lcd.print("INA219 OK!");
  }

  vTaskDelay(1000 / portTICK_PERIOD_MS);

  // Initialize SD Card
  if (!SD.begin(sdChipSelect)) {
    lcd.setCursor(0, 1);
    lcd.print("SD FAIL!");
    Serial.println("SD Card initialization failed!");
    while (1);  // Halt system if SD fails
  } else {
    lcd.clear();
    lcd.setCursor(0, 1);
    lcd.print("SD OK!");
  }

  vTaskDelay(1000 / portTICK_PERIOD_MS);

  xSemaphoreGive(task1Semaphore);

  vTaskDelete(NULL);
}

/**
 * @brief      Task to read sensor data and save it to SD card.
 *
 *             This task waits for the task1Semaphore to be given, then
 *             enters an infinite loop where it reads the sensor data using
 *             readSensor() and saves it to the SD card using saveDataSensor().
 *             Then it waits for 3 seconds using vTaskDelay() before repeating
 *             the process.
 *
 * @param[in]  parameter  Unused parameter
 */
void readSensorTask(void* parameter) {
  xSemaphoreTake(task1Semaphore, portMAX_DELAY);
  for (;;) {
    readSensor();
    saveDataSensor();
    vTaskDelay(3000 / portTICK_PERIOD_MS);    // Read 3 sec delay
  }
}

/**
 * @brief Task to log sensor data to storage.
 *
 *        This task runs indefinitely, repeatedly calling the storeData() 
 *        function to log sensor data. The concept of sending data to the 
 *        cloud is indicated by the commented-out sendToCloudTask() call. 
 *        The task includes a 10 ms delay between each iteration to manage 
 *        task scheduling and CPU usage.
 *
 * @param[in] parameter Unused parameter
 */

void logDataTask(void* parameter) {
  for (;;) {
    storeData();
    // sendToCloudTask();     just concept
    vTaskDelay(10 / portTICK_PERIOD_MS);
  }
}

void setup() {
  Serial.begin(SERIAL_BAUD);
  ESP_LOGI("SYSTEM LOG", "INFO: Bootup. Serial started.");
  initLcd();

  SendQueue = xQueueCreate(1000, sizeof(SensorData));
  task1Semaphore = xSemaphoreCreateBinary();
  task2Semaphore = xSemaphoreCreateBinary();

  xTaskCreate(wifiAndTimeTask, "Init all sensor, Read Time and Sync RTC", 10000, NULL, 1, &wifiAndTimeTaskHandle);
  xTaskCreate(readSensorTask, "Read Sensor", 10000, NULL, 1, &readSensorTaskHandle);
  xTaskCreate(logDataTask, "Logger", 10000, NULL, 1, &logDataTaskHandle);
}

void loop() {
  vTaskDelete(NULL);
}

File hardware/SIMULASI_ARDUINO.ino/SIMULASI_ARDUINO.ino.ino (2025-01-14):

#include <Wire.h>
#include <Adafruit_ADS1X15.h>
#include <LiquidCrystal_I2C.h>

#define PGA 0.602
#define acsOffset 1.67
#define acsSens 0.0134
#define lsb 0.0000763

// Inisialisasi objek LCD (alamat I2C 0x27 untuk LCD 16x2)
LiquidCrystal_I2C lcd(0x27, 16, 2);

// Inisialisasi objek ADS1115 (alamat I2C default adalah 0x48)
Adafruit_ADS1115 ads;

float getChannel0(){
  float rawA0;
  return rawA0 = ads.readADC_SingleEnded(0); 
}

float getChannel2(){
  float rawA2;
  return  rawA2 = ads.readADC_SingleEnded(2);
}

float getVoltFromRaw(){
  float rawAds0 = getChannel0();
  // Serial.println("ADS0: " + String(rawAds0));
  float realVolt1 = (rawAds0 * lsb) / PGA;
  // Serial.println("VOLT1: " + String(realVolt1));
  return realVolt1 * 10;
}

float getCurrentFromRaw(){
  float rawAds2 = getChannel2();
  float realVolt2 = (rawAds2 * lsb) / PGA;
  return (realVolt2 - acsOffset) / acsSens;
}

float getPower(){
  return getVoltFromRaw() * getCurrentFromRaw();
}

void setup() {
  // Mulai komunikasi I2C
  Wire.begin();
  
  // Inisialisasi LCD
  lcd.begin(16, 2);
  lcd.backlight();
  
  // Inisialisasi ADS1115
  if (!ads.begin()) {
    lcd.print("Tidak ada ADS");
    while (1);
  }

  // Set gain menjadi 1 (±4.096V)
  ads.setGain(GAIN_ONE);

  // Tampilkan pesan awal di LCD
  lcd.setCursor(0, 0);
  lcd.print("Mengambil data...");
}

void loop() {
  lcd.clear();  // Bersihkan layar LCD
  
  // Menampilkan nilai channel A0
  lcd.setCursor(0, 0);  // Baris pertama, kolom pertama
  lcd.print("V:");
  lcd.print(getVoltFromRaw());
  lcd.print("V");

  // Menampilkan nilai channel A2
  lcd.setCursor(9, 0);
  lcd.print("I:");
  lcd.print(getCurrentFromRaw());
  lcd.print("A");

  lcd.setCursor(0, 1);
  lcd.print("Power:");
  lcd.print(getPower());
  lcd.print("W");



  // Delay sebelum pembacaan berikutnya
  delay(1000);  // 1 detik
}
